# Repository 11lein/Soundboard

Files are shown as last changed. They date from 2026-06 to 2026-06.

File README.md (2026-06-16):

# 🚗 Soundboard für den Carbage Run

## 🎯 Motivation

Beim **Carbage Run** – einer Rallye mit Schrottautos – haben viele Teilnehmer Fanfaren, Megafone oder lustige Sounds abgespielt.  
Wir hatten zwar bereits ein Megafon mit Line-In und Bluetooth, aber:

> 🎛️ "Wenn ich hupen will, will ich auf einen Knopf hauen – nicht erst das Handy entsperren!"

Deshalb: ein eigenständiges Soundboard mit 25 Tasten, SD-Karte und Sofortreaktion.

---

## 📸 Vorschau

### Gehäuse (3D-gedruckt)

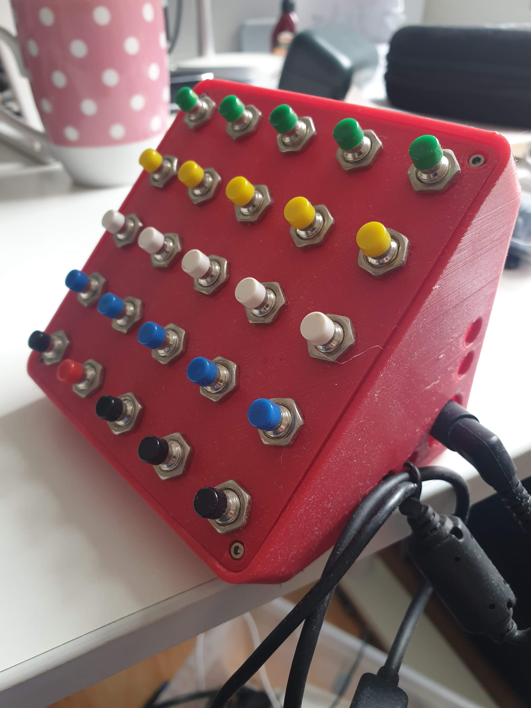
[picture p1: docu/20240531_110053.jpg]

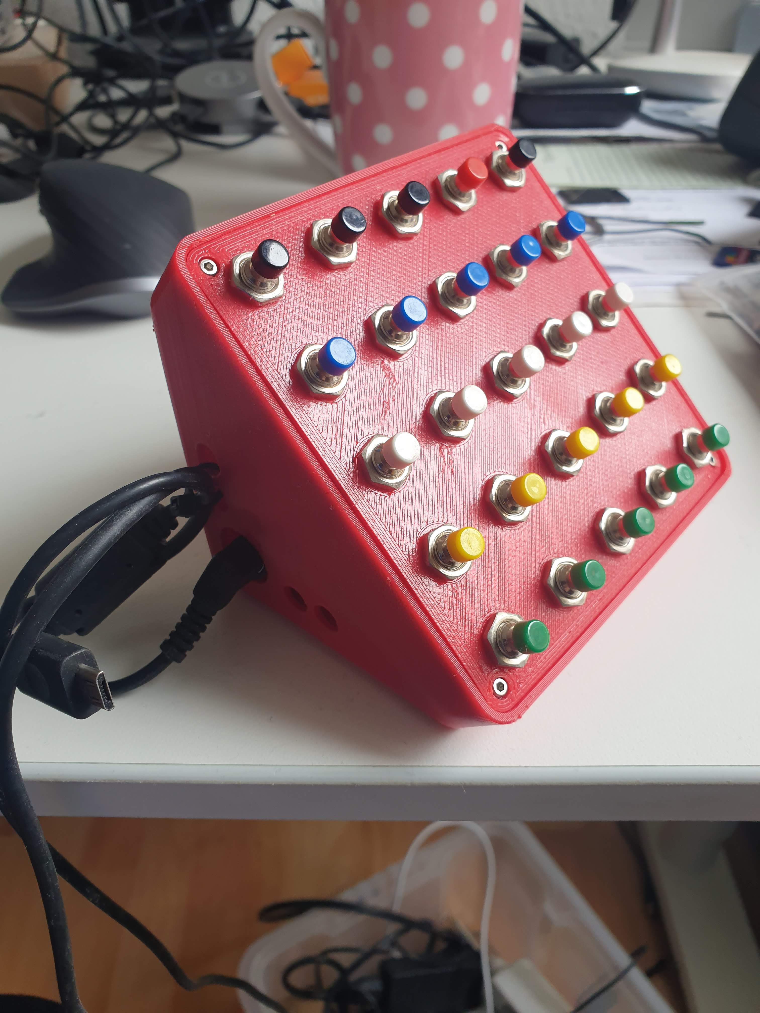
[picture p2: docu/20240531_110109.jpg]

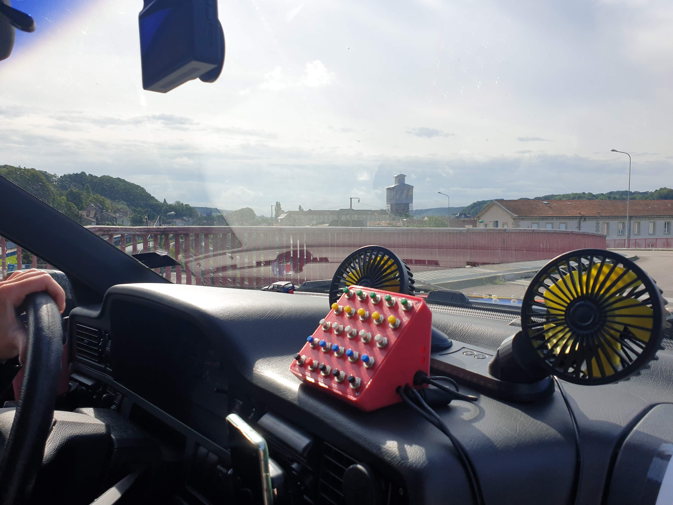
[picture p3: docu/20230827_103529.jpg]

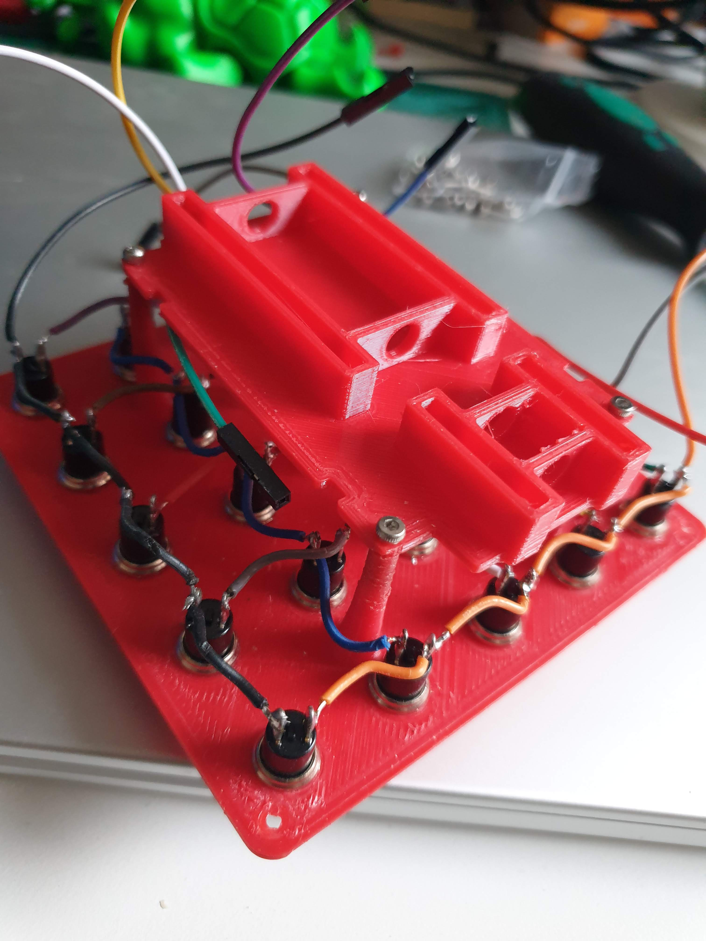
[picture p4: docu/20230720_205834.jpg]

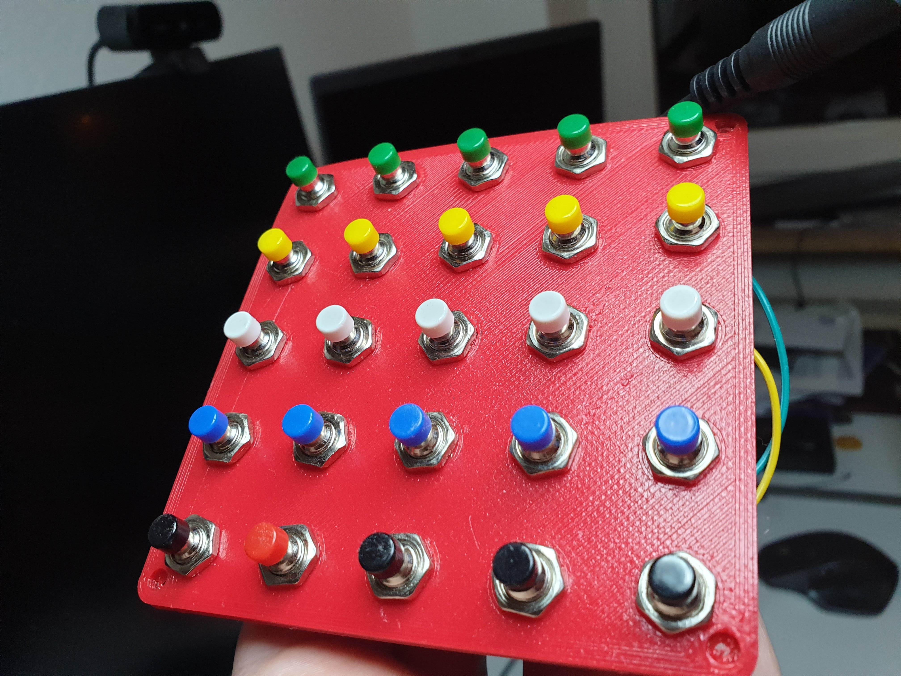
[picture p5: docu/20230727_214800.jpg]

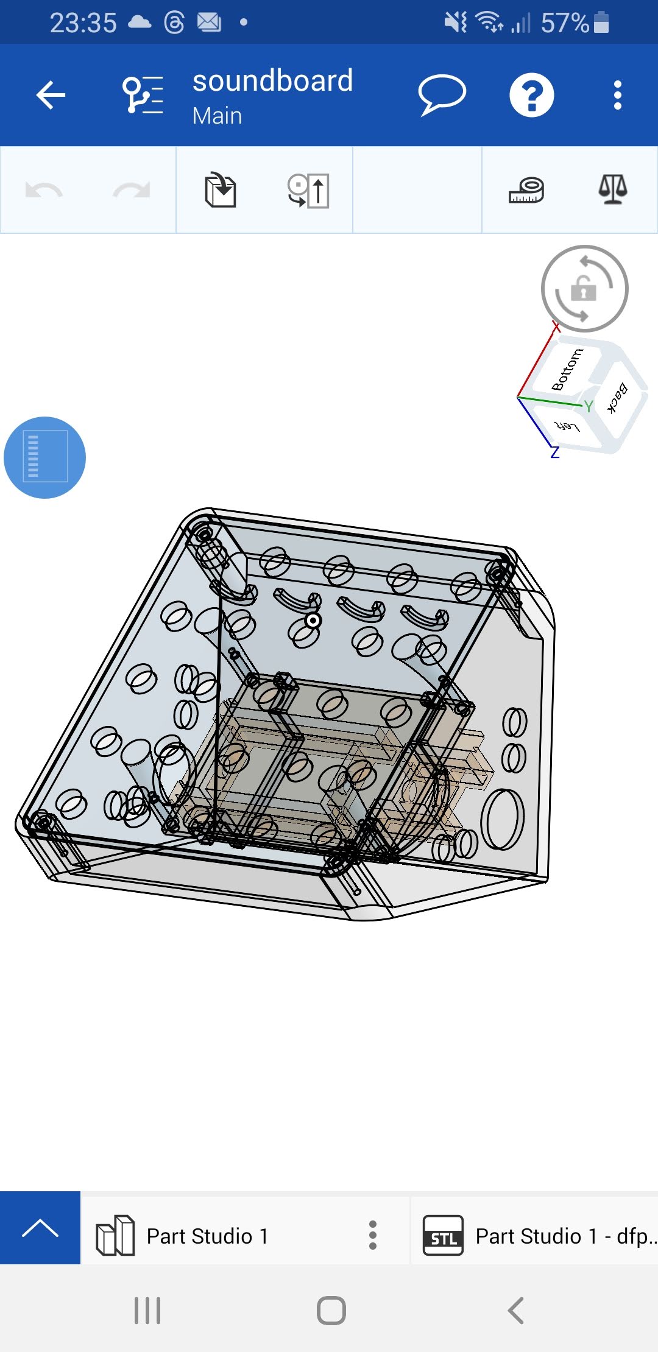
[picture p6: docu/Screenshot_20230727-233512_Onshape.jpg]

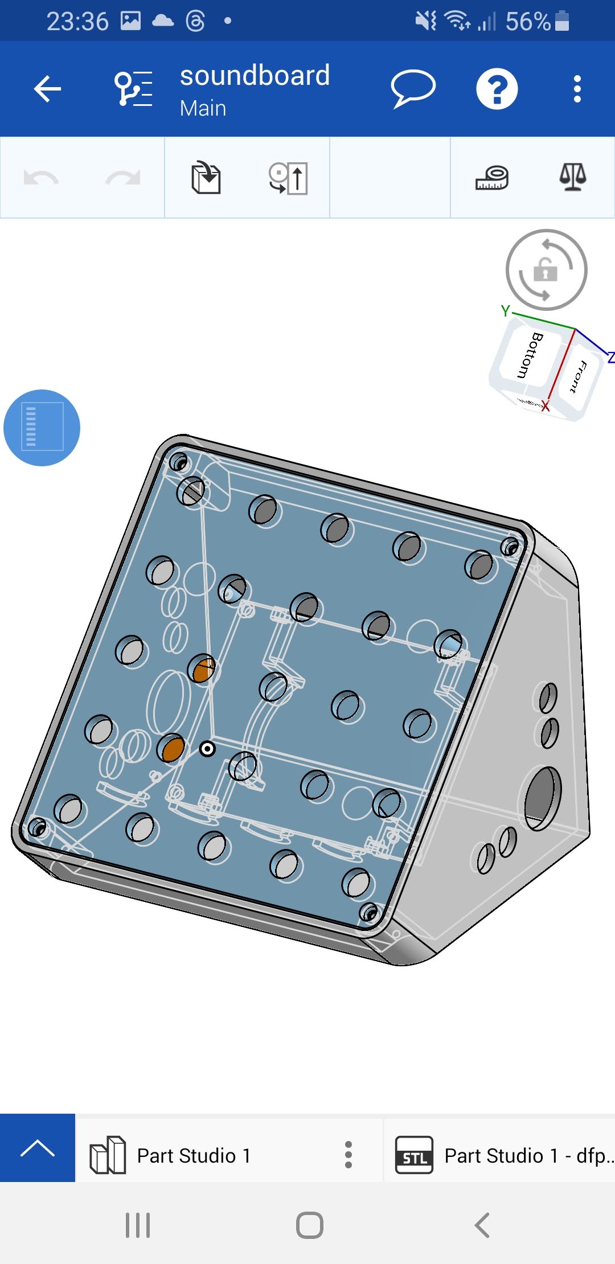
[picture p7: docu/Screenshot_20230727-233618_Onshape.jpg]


### Innenleben
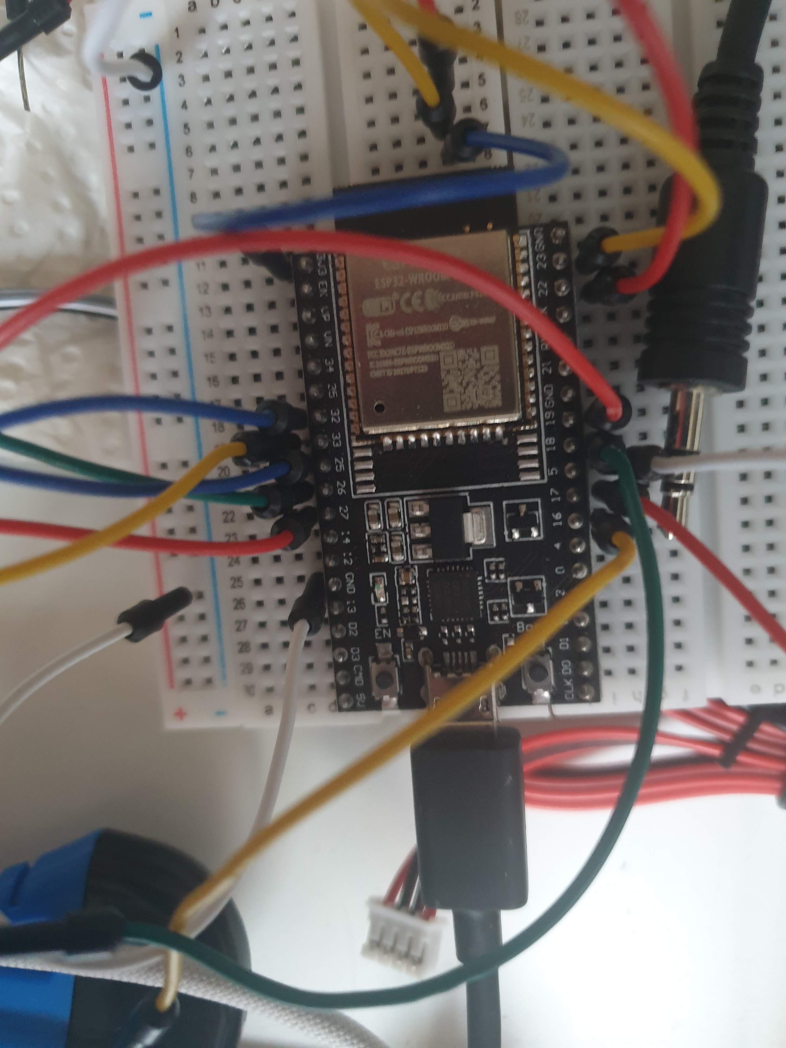
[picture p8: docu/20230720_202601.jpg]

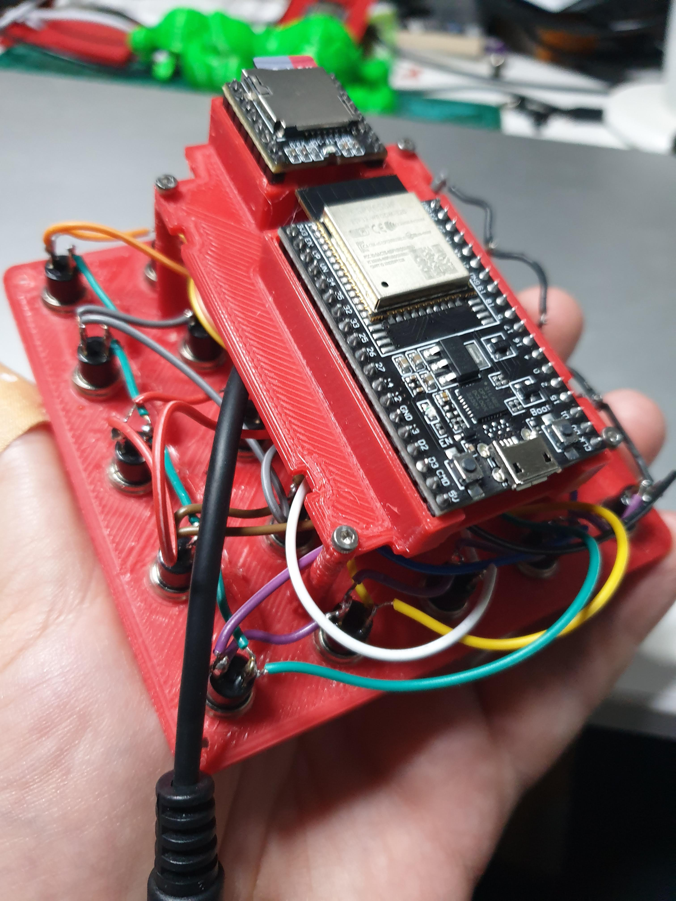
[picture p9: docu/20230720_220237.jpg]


> Alle Bilder findest du im Ordner `docu/`. Der aktuelle Verdrahtungsplan steht
> weiter unten im Abschnitt [Schaltung](#-schaltung).

---

## ⚙️ Features

- 🎵 **24 Soundtasten** (A–X) in 5×5 Matrix für direkte Soundauswahl
- 🔁 **Sechsfachbelegung:** `Y` = Mode-Taste + Halten → **144 Sounds** (6 Bänke)
- 💾 **DFPlayer Mini** spielt MP3s direkt von SD-Karte
- 📡 **Bluetooth**-Steuerung per Smartphone-App oder Terminal (alle 144 Tracks)
- 🧠 **ESP32** mit frei programmierbarer Logik
- 🧰 [**3D-gedrucktes Gehäuse**](https://cad.onshape.com/documents/51f835b686c64aa4e062ca5b/w/735ce97b22fc647d3e8dc544/e/93c6d67ebc2946beec692255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)

---

## 🧠 Schaltung

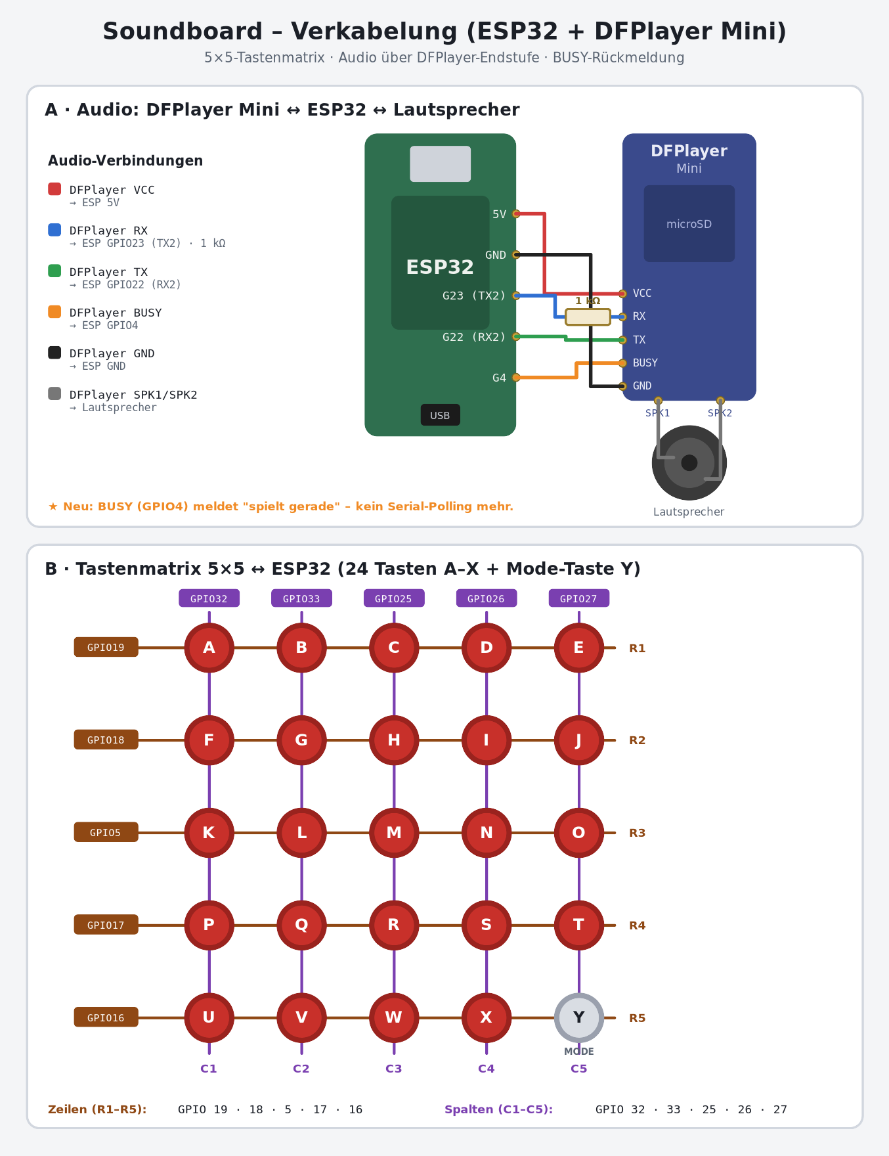
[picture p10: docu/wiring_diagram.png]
Verkabelung


> Aktueller Verdrahtungsplan mit **DFPlayer Mini** (inkl. **BUSY → GPIO4**) und der
> 5×5-Tastenmatrix. Quelle als SVG (`docu/wiring_diagram.svg`) bzw. zum Neuerzeugen
> `docu/gen_wiring.py` (rendert das SVG aus den Pin-Belegungen in `src/main.cpp`).
> Der frühere Wokwi-Entwurf (`docu/wokwi/`) nutzte ein SD-Kartenmodul als Platzhalter
> und ist nicht mehr aktuell.

### 🔘 Tastenanschlüsse

| Zeile (row) | ESP32 Pin |
|---|---|
| R1 | D19 |
| R2 | D18 |
| R3 | D5 |
| R4 | D17 |
| R5 | D16 |

| Spalte (col) | ESP32 Pin |
|---|---|
| C1 | D32 |
| C2 | D33 |
| C3 | D25 |
| C4 | D26 |
| C5 | D27 |

### 🎧 DFPlayer Mini Anschluss 
Für die korrekte Verkabelung siehe
[DFPlayer Mini Dokumentation](https://www.elektronik-kompendium.de/sites/praxis/bauteil_dfplayer-mini.htm)

| DFPlayer Pin | ESP32 Pin |
|---|---|
| TX | GPIO22 |
| RX | GPIO23 **(über 1 kΩ in Reihe)** |
| BUSY | GPIO4 |
| VCC | 5V |
| GND | GND |
|----| **Endstufe**|
| SPK1 | Left Audio  |
| GND | GND Audio |
| SPK2 | Right Audio |

> Der **1 kΩ-Widerstand** in der RX-Leitung (ESP-TX → DFPlayer-RX) dämpft Störungen
> und schützt den DFPlayer-Eingang – eine gängige Empfehlung für stabile UART-Kommunikation.

💾 SD-Karte:  
MP3-Dateien im MP3-Verzeichnis, benannt nach `Bank*100 + Position`:
Bank 1 = `0101`–`0124`, Bank 2 = `0201`–`0224`, … Bank 6 = `0601`–`0624` (24 pro Bank).

---

## 🎮 Bedienung

### Tasten (A–X) + Mode-Taste `Y`

`Y` spielt keinen Sound, sondern wählt die Bank-Gruppe. Eine Soundtaste **kurz** drücken oder **halten** wählt innerhalb der Gruppe die Bank:

| `Y`-Status | Soundtaste kurz | Soundtaste halten |
|---|---|---|
| – (Standard) | Bank 1 (`0101`–`0124`) | Bank 2 (`0201`–`0224`) |
| `Y` kurz tippen | Bank 3 (`0301`–`0324`) | Bank 4 (`0401`–`0424`) |
| `Y` halten | Bank 5 (`0501`–`0524`) | Bank 6 (`0601`–`0624`) |

- Tracknummer = **Bank × 100 + Position**. Taste **A** = Position 1, … **X** = Position 24.
- Der gewählte Mode gilt **für den nächsten Sound** und springt danach sofort auf Standard (Bank 1 & 2) zurück. Ohne Tastendruck resettet er automatisch **nach 10 s**; erneutes `Y` schaltet ebenfalls zurück.
- Dieselbe Taste während der Wiedergabe erneut drücken = **Stop**.

### 📡 Bluetooth-Befehle

Zahl (mit `\n`) an das Gerät `das_11lein` senden. Die Tracknummer enthält die Bank direkt – einfach die Nummer senden.

| Eingabe | Aktion |
|---|---|
| `101`–`624` | Track direkt abspielen (z. B. `305` = Bank 3, Taste E) |
| `700`–`6999` | Zusatz-/Parkplatz-Track (`0700`…), nur über die App, kein Hardware-Knopf |
| `7000`–`7100` | Lautstärke auf `(Wert−7000)` Prozent setzen (0–100 %) |
| `9999` | Stop |
| `9998` / `9997` / `9996` | Lautstärke 33 / 67 / 100 % (Kompatibilität) |
| `9995` | Neustart |

> Die Befehlscodes liegen bei `9999` absteigend – weit über jeder Tracknummer, daher keine Kollision.

Die zuletzt gesetzte Lautstärke wird im Flash (NVS) gespeichert und beim Booten
wiederhergestellt. Beim Verbinden sendet der ESP einmal `READY vol=<n>`, damit die
App den aktuellen Stand kennt. WiFi ist deaktiviert (das Gerät nutzt nur Bluetooth).

---

## 📂 Projektstruktur

```text
/
├── src/
│   ├── MP3/                # Arduino-Quellcode
│   └── main.cpp
├── printfiles/         # STL-Dateien für 3D-Druck
├── docu/               # Fotos, Schaltpläne, Screenshots
└── README.md

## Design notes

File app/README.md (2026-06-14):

# 📱 Soundboard Remote (Flutter, Android)

Flutter-App zur **Fernsteuerung des ESP32-Soundboards über Bluetooth Classic (SPP)**.
Spiegelt das physische Gerät: 6 Bänke, je ein 5×5-Raster mit den echten Tastenfarben.

<p align="center">
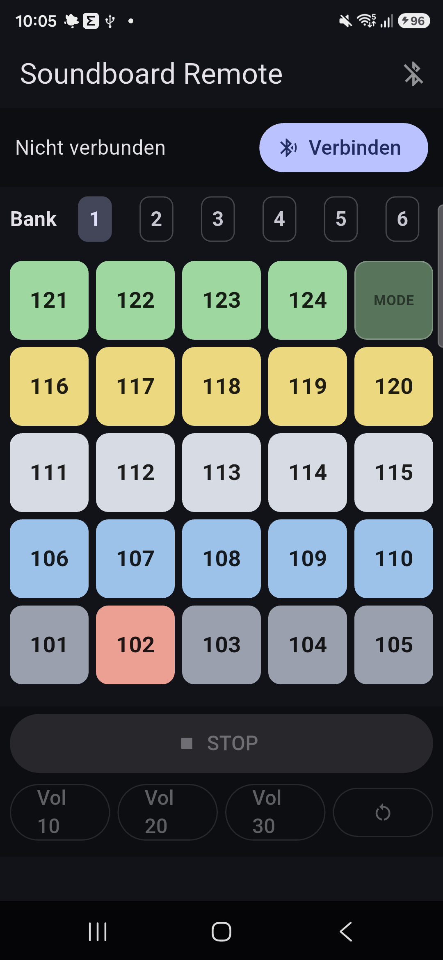
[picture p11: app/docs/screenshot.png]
Soundboard Remote – Bank 1 (Tracks 101–124)
  
</p>

## Funktion

- 🔵 **Verbinden** mit dem gekoppelten Gerät `das_11lein` (gekoppelte Geräte werden
  gelistet – vorher einmal in den Android-Bluetooth-Einstellungen koppeln).
- 🎛️ **6 Bänke** wählbar; pro Bank ein 5×5-Raster (Position unten links beginnend,
  oben rechts = Mode-Taste, nicht belegbar), eingefärbt nach der physischen
  Tastenfarbe.
- ▶️ Tippen sendet die Tracknummer **`Bank*100 + Position`** (`101`–`624`).
- 🔈 **Lautstärke** 10/20/30, ⏹ **Stop**, ↻ **Neustart** – als Befehle `9999`
  absteigend (siehe Firmware-Protokoll).

## Architektur

- `lib/soundboard_controller.dart` – Verbindungs-/Sende-Logik (`ChangeNotifier`),
  spricht über den Platform-Channel `soundboard/bt`.
- `lib/home_page.dart` – UI (Verbindungsleiste, Bank-Auswahl, Raster, Steuerung).
- `android/.../MainActivity.kt` – nativer **SPP-Channel** (BluetoothSocket via
  RFCOMM-UUID `00001101-…`). Bewusst kein Drittanbieter-BT-Plugin, damit der
  Build mit aktuellem AGP/Gradle sauber durchläuft.
- `assets/key-colors.json` – Tastenfarben (Kopie aus dem `mp3-sorter`-Tool).

Berechtigung: `BLUETOOTH_CONNECT` (Android 12+) wird zur Laufzeit über
`permission_handler` angefragt; nur gekoppelte Geräte, kein Scan/Location nötig.

## App installieren

### Android – APK direkt (empfohlen, kein Google Play nötig)

Eine fertig gebaute APK liegt im Repo unter `app/soundboard-remote.apk`.

1. APK auf das Telefon übertragen (USB-Kabel, Bluetooth-Dateiübertragung oder
   Cloud-Dienst deiner Wahl).
2. Auf dem Telefon: **Einstellungen → Apps → Sonderrechte → Unbekannte Quellen**
   (auf manchen Geräten: *Unbekannte Apps installieren*) für den Datei-Manager oder
   Browser aktivieren, mit dem du die APK öffnest.
3. Die APK antippen → installieren.
4. Nach der Installation einmal den Bluetooth-Namen `das_11lein` in den
   Android-Bluetooth-Einstellungen koppeln, dann die App öffnen.

> Android-Hilfe: [support.google.com – Apps aus anderen Quellen installieren](https://support.google.com/android/answer/7680439)

### iPhone / iOS – nicht direkt unterstützt

Bluetooth Classic (SPP/RFCOMM) wird von iOS **nicht unterstützt** – Apple erlaubt
App-seitig nur Bluetooth Low Energy (BLE) sowie proprietäre MFi-Protokolle.
Der ESP32 nutzt klassisches SPP, das auf iPhone grundsätzlich nicht aus Apps
heraus erreichbar ist (weder über den App Store noch per Sideload).

Optionen, falls du doch ein iOS-Gerät nutzen möchtest:

- **ESP32 auf BLE umrüsten**: Die Firmware auf BLE-UART (z. B. Nordic UART Service)
  umstellen; dann kann eine angepasste Flutter-App über `flutter_blue_plus` sprechen.
  Aufwand: mittlerer Firmware-Umbau.
- **Webbrowser-Steuerung**: ESP32 als WLAN-Access-Point mit einer kleinen
  Web-Seite; dann reicht Safari auf dem iPhone. Kein Bluetooth nötig.

> iOS-Referenz zu Bluetooth-Einschränkungen: [developer.apple.com – Core Bluetooth](https://developer.apple.com/documentation/corebluetooth)

---

## Selbst bauen & Installieren

> ⚠️ **Wichtig:** Android-/Gradle-Builds scheitern an Leerzeichen/Klammern im Pfad.
> Dieses Repo liegt unter `…/Soundboard (Kopie)/`, daher **nicht hier direkt
> bauen**. Projekt an einen Pfad **ohne Leerzeichen** kopieren (z. B.
> `~/soundboard_remote`) und dort bauen.

Voraussetzungen: Flutter SDK, Android SDK (`platforms;android-35`,
`build-tools;35.0.0`), **JDK 17** (eine JRE reicht nicht – `javac` nötig).

```bash
cp -r app ~/soundboard_remote && cd ~/soundboard_remote
export JAVA_HOME=/pfad/zur/jdk-17
flutter pub get
flutter build apk --release        # build/app/outputs/flutter-apk/app-release.apk
# auf ein angeschlossenes Telefon:
flutter install                    # oder: adb install -r app-release.apk
```

## Protokoll (muss zur Firmware passen)

| Senden | Wirkung |
|---|---|
| `101`–`624` | Track abspielen (`Bank*100 + Position`) |
| `9999` | Stop |
| `9998` / `9997` / `9996` | Lautstärke 10 / 20 / 30 |
| `9995` | Neustart |

Jeweils als ASCII-Zahl mit abschließendem `\n`.

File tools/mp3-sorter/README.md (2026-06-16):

# 🎚️ MP3 Sorter

Plattformübergreifendes Desktop-Tool (Mac / Linux / Windows) zum Sortieren der
Soundboard-MP3s per **Drag & Drop**. Die Dateien werden für das DFPlayer-Schema
`Bank*100 + Position` vorbereitet – Bank 1 = `0101`–`0124`, … Bank 6 =
`0601`–`0624` (6 Bänke × 24 = 144 Slots).

## Features

- 🖱️ **Drag & Drop:** Ordner oder MP3s ins Fenster ziehen zum Laden/Hinzufügen,
  Zeilen ziehen zum Umsortieren.
- 🔢 **Prefix-Sortierung:** Dateien mit gültigem `Bank*100+Pos`-Prefix (z. B.
  `0101_`, `0305_`) landen auf ihrem Slot; Dateien ohne (oder mit altem) Prefix
  werden alphabetisch dahinter einsortiert.
- 🏦 **Ansicht wie das PDF:** **ein** 5×5-Raster (dem Kasten nachempfunden, unten
  links beginnend, oben rechts die nicht belegbare Mode-Taste). Jede Taste zeigt
  **6 Zeilen** – eine je Bank – mit Dateiname (ohne Prefix/Endung) und
  **Play-Knopf** statt Nummer. Zellen sind nach der physischen Tastenfarbe
  eingefärbt.
- 🅿️ **Parkplätze:** Dateien **ohne** gültigen Prefix landen unten in Parkplätzen
  (Reihen aus 5 Boxen × 6 Zeilen, alphabetisch, mit Play). Zieht man eine Datei
  aus dem Raster hierher, wird ihr **Prefix entfernt** (sie wird wieder unsortiert).
- 🎨 **Farb-Kodierung:** Die physische Tastenfarbe (oben Grün, dann Gelb, Weiß,
  Blau, unten Schwarz – 2. von links Rot) liegt als
  [`lib/key-colors.json`](lib/key-colors.json) im Projekt und färbt Raster und PDF.
- ✏️ **Umbenennen (Suchen & Ersetzen):** Button öffnet einen Dialog mit
  Suchen/Ersetzen, **Regex**- und **Groß/Klein**-Checkbox (Default: ignoriert).
  Eine **2-Spalten-Vorschau** zeigt nur die betroffenen Dateien zum Bestätigen.
- ⚡ **Quick-Rename:** **Doppelklick** auf einen Titel benennt ihn direkt inline
  um (Enter = speichern, Esc = abbrechen).
- 🗑️ **Papierkorb:** Eine Kachel unten; hierhin gezogene Dateien werden beim
  **Final speichern** von der Festplatte gelöscht (mit ↩ Wiederherstellen je Eintrag).
- ⏱️ **Hover-Info:** Beim Überfahren einer Zeile werden **Dauer und Bitrate** der MP3 angezeigt.
- 📋 **Liste exportieren:** Schreibt platzierte **und geparkte** Titel als JSON
  (`soundboard-liste_…json`, Nummer → Titel) – zum Import in die App. Parkplätze
  bekommen dabei alphabetisch die Nummern **`700`+** (nur in der App nutzbar).
- 📥 **Liste importieren:** Lädt eine (in der App bearbeitete) Titel-JSON und
  überträgt die Titel auf die Dateien der passenden Slots – das anschließende
  **Final speichern** benennt entsprechend um (Round-Trip App ⇄ Sorter).
- 💳 **Auf SD-Karte schieben:** Wechseldatenträger auswählen, optional **vorher
  formatieren** (mit Nachfrage; sofern das OS es unterstützt), dann die Dateien in
  den `MP3/`-Ordner der Karte kopieren – platzierte als `0101_…`, geparkte als `0700_…`.
- 🔄 **Aktualisieren:** Liest den aktuellen Ordner neu von der Platte (neue/entfernte
  Dateien) und behält die Anordnung. Der **zuletzt geöffnete Ordner** wird gemerkt
  und beim Start automatisch wieder geöffnet.
- ▶️ **Vorhören:** Play-Knopf pro Zeile, der während der Wiedergabe zur Pause
  wird. Ein anderer Sound stoppt alle übrigen und setzt sie auf 0 s zurück – nur
  der aktuelle Titel merkt sich seine Pause.
- 🖨️ **PDF-Export & Vorschau (A4 quer):** Erzeugt eine Belegungs-Übersicht als
  5×5-Raster (mit den Tastenfarben als Hintergrund), wobei **jede Tastenzelle
  alle 6 Bänke** untereinander zeigt (Bank-Nummer + Dateiname **ohne**
  Prefix/Endung, einzeilig abgeschnitten, kein Umbruch). Ohne Überschrift, Zellen
  exakt 6 Zeilen hoch (Tabelle nicht seitenfüllend). **👁️ Vorschau** öffnet das
  fertige PDF in einem Fenster, bevor du speicherst.
- 💾 **Zwischenspeichern:** Der aktuelle Stand wird als `.mp3sorter.json` im
  Ordner gespeichert – **ohne** die Dateien anzufassen. Beim erneuten Öffnen
  wird dieser Entwurf wiederhergestellt.
- ✅ **Final speichern:** Erst hier werden die Dateien auf der Festplatte
  umbenannt (4-stelliger Prefix `NNNN_`). Kollisionssicher durch zweiphasiges
  Umbenennen (z. B. bei einem Tausch).

## Starten per Doppelklick

Voraussetzung: **Node.js/npm** ist installiert (https://nodejs.org). Beim ersten
Start werden die Abhängigkeiten automatisch geholt.

| Betriebssystem | Datei doppelklicken |
|---|---|
| 🪟 Windows | `start.bat` |
| 🍎 macOS | `start.command` |
| 🐧 Linux | `start.sh` |

> - **macOS:** Beim ersten Mal evtl. Rechtsklick → „Öffnen" (Gatekeeper).
> - **Linux:** Im Dateimanager ggf. „Ausführen erlauben" aktivieren bzw. beim
>   Doppelklick „Run/Ausführen" wählen.

## Start (Entwicklung / Terminal)

```bash
cd tools/mp3-sorter
npm install
npm start
```

> Hinweis Linux: Falls `ELECTRON_RUN_AS_NODE` in der Umgebung gesetzt ist, vorher
> entfernen: `env -u ELECTRON_RUN_AS_NODE npm start` (die Doppelklick-Starter
> erledigen das bereits selbst).

## Tests

```bash
npm test          # Unit-Tests der Sortier-/Namenslogik (node --test)
npm run test:smoke   # Electron-Smoketest: prüft, dass window.api vollständig
                     # bereitsteht und der "Ordner öffnen"-IPC-Pfad funktioniert
```

> Der Smoketest braucht eine Anzeige (DISPLAY) und ein echtes Electron; in
> Umgebungen mit gesetztem `ELECTRON_RUN_AS_NODE` davor entfernen.

## Installer bauen

```bash
npm run dist     # erzeugt dmg (mac) / nsis (win) / AppImage (linux) in dist/
```

## So funktioniert das Umbenennen

`finalName(slot, datei)` entfernt einen vorhandenen `NNNN_`-Prefix und setzt den
neuen `Bank*100+Pos`-Prefix davor – der beschreibende Teil bleibt erhalten:

```
Slot 1  + "0099_clownhorn.mp3"  ->  "0101_clownhorn.mp3"   (Bank 1, Pos 1)
Slot 25 + "airhorn.mp3"          ->  "0201_airhorn.mp3"     (Bank 2, Pos 1)
```

Die eigentliche Sortier-/Namenslogik liegt in [`lib/naming.js`](lib/naming.js)
und ist unabhängig von der GUI testbar.

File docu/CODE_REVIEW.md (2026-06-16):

# Code-Review: Soundboard

Analyse des Gesamtprojekts (ESP32-Firmware, Flutter-App, Electron-MP3-Sorter)
nach **Performance**, **Sicherheit**, **Coding-Guidelines** und **Linting**,
plus eine Bestandsaufnahme der Code-Kommentierung. Stand: 2026-06.

> Hinweis zur Verifikation: In der Review-/Web-Umgebung waren nur **Node.js +
> npm** verfügbar. Das Electron-Tool ist daher voll getestet (Unit-Tests,
> ESLint, Smoke-Test). **Flutter/Dart** und **PlatformIO** fehlten, d.h.
> Firmware und App konnten hier *nicht* kompiliert werden – Änderungen daran
> wurden bewusst konservativ gehalten und müssen lokal mit `flutter analyze` /
> `flutter test` bzw. `pio run` gegengeprüft werden.

## Gesamteindruck

Der Code ist insgesamt **überdurchschnittlich gepflegt**: durchdachte
Architektur, gute Trennung der drei Komponenten und – anders als oft – bereits
**dichte, sinnvolle Kommentierung** der nicht-offensichtlichen Stellen
(Bank-/Mode-Mathematik, deferred NVS-Write, BT-Overflow-Schutz, Reconnect-Logik,
PDF-Layout). Die wesentlichen Lücken lagen weniger bei „fehlenden Kommentaren"
als bei **fehlendem Linting** (Electron) und einem **inkonsistenten Path-Handling**
(Electron) sowie einer **sehr großen UI-Datei** (`app/lib/home_page.dart`).

| Komponente | Performance | Sicherheit | Guidelines | Linting |
|---|---|---|---|---|
| Firmware (`src/main.cpp`) | gut | gut (per Design) | gut | – (kein C++-Linter eingerichtet) |
| Flutter-App (`app/`) | gut | gut | mittel (Monolith) | flutter_lints (Default) |
| Electron (`tools/mp3-sorter/`) | gut | mittel → **gehärtet** | gut | **fehlte → eingeführt** |

---

## 1. Firmware — `src/main.cpp`

ESP32 / Arduino, ~330 Zeilen, eine `.cpp`. Sehr klar gegliedert und gut
kommentiert.

### Performance
- **Keine blockierenden Delays im `loop()`**; Timing über `millis()`-Stempel.
  Das einzige `delay(1000)` steckt in der DFPlayer-Init-Retry-Schleife in
  `setup()` (einmalig beim Boot) – akzeptabel und kommentiert.
- **Deferred NVS-Write** für die Lautstärke (`volumeDirty` + `VOLUME_SAVE_DELAY_MS`,
  `main.cpp:88`) verhindert Flash-Blockaden bei schnellem +5/−5-Tippen. Sehr gut.
- **Nicht-blockierender BT-Zeilenleser** mit fixem 8-Byte-Puffer (`main.cpp:256`)
  – keine Heap-Fragmentierung, sauberer Overflow-Schutz.

### Sicherheit
- **Kein Bluetooth-Auth** und **Remote-Reset (`9995`)** ohne Bestätigung
  (`main.cpp:305`). Das ist **bewusst so** (vertrauenswürdiges Umfeld, ein
  Carbage-Run-Auto) und in `AGENTS.md` dokumentiert. Threat-Model akzeptiert;
  als Restrisiko vermerkt (ein gekoppeltes Gerät kann Stop/Volume/Reset senden).
- **Eingabevalidierung** ist solide: `atoi` + `if (input > 0)`, Bereichsprüfung
  für Tracks/Volume (`main.cpp:285`, `310`), Overflow-Zeilen werden verworfen
  statt abgeschnitten (`main.cpp:264`, `329`). Nicht existente Tracks lässt der
  DFPlayer still fallen (kein Crash).

### Coding-Guidelines
- `keys`, `rowPins`, `colPins` (`main.cpp:57–65`) sind nicht `const`. **Bewusst
  nicht geändert:** der `Keypad`-Konstruktor nimmt nicht-`const`-Zeiger
  (`char*`, `byte*`), `const`-Pin-Arrays würden ohne Cast die Kompilierung
  brechen. Niedrige Priorität.
- Leichte Duplizierung bei den Kompat-Volume-Befehlen (`main.cpp:290–303`) –
  vertretbar, gut lesbar; kein Umbau nötig.
- Naming `mySerial` / `myDFPlayer` ist Arduino-üblich; rein kosmetisch.

### Umgesetzt (Kommentare, null Verhaltensänderung)
- `isPlaying()`: Unzuverlässigkeit des BUSY-Pins explizit dokumentiert und warum
  er nur für den Stop-Toggle taugt.
- Erläutert, warum `lastKey` nach einem Stop genullt wird.

---

## 2. Flutter-App — `app/`

Sauberes `ChangeNotifier`-Modell. `soundboard_controller.dart` (BT-State,
Protokoll, Reconnect-Watchdog) ist **vorbildlich kommentiert**. Native SPP-Anbindung
in Kotlin (`MainActivity.kt`) mit korrektem Threading und Exception-Handling.

### Performance
- `ListenableBuilder` auf `[controller, AppSettings]` (`home_page.dart`), Tabs via
  `KeepAlive`/`AutomaticKeepAliveClientMixin` am Leben gehalten – gut.
- **Watchdog 700 ms** (`soundboard_controller.dart:125`) mit 3-s-Throttle für
  stille Reconnects – vernünftig. *Empfehlung:* exponentielles Backoff, falls das
  Gerät dauerhaft aus ist (Akku).
- `wrapKeyTitle()` lief bisher pro Tile/Frame. Durch Auslagern als reine Funktion
  ist es jetzt **cachebar** (Empfehlung: Ergebnis pro `TrackEntry` memoisieren).

### Sicherheit
- Laufzeit-Berechtigungen (`Permission.bluetoothConnect`) inkl. „dauerhaft
  abgelehnt"-Pfad sauber behandelt (`soundboard_controller.dart:317`).
- Nur **gekoppelte** Geräte, fixe SPP-UUID; keine Secrets in `SharedPreferences`.
- *Empfehlung (Kotlin):* `s.connect()` ohne Timeout (`MainActivity.kt`) kann den
  Connect-Thread bis zum OS-Timeout (~20 s) hängen lassen → `withTimeoutOrNull`.

### Coding-Guidelines
- **Hauptbefund:** `home_page.dart` war mit **1193 Zeilen** ein Monolith
  (Grid, Controls, Dialoge, Suche, Menüs in einem `State`).
- Vereinzelt stille `catch (_)` ohne Begründung.

### Linting
- `analysis_options.yaml` nutzte nur das Default-`flutter_lints` ohne eigene
  Regeln.

### Umgesetzt
- **`home_page.dart` verschlankt:** die drei sicher und mechanisch
  extrahierbaren Teile nach `lib/widgets/` ausgelagert – `wrapKeyTitle()`
  (`key_title.dart`, jetzt unit-getestet), `KeepAlive`, `PlayPulse`.
  Verhaltensneutral (Verbatim-Move + Referenz-Rename).
- **Test** `test/key_title_test.dart` für die Umbruch-Invarianten.
- **Lint-Regeln** in `analysis_options.yaml` aktiviert (single quotes, const,
  final locals, no print, …) – stilkonform.
- Begründungs-Kommentare an den verbleibenden `catch (_)` im Controller.

### Offene Empfehlung (Follow-up mit Compiler)
Der tiefere Split der **zustandsbehafteten** Builder-Methoden
(`_grid`/`_key`/`_controls`/`_bankSelector`) in eigene `StatelessWidget`s wurde
**bewusst nicht** in dieser Umgebung gemacht: er erfordert das Durchreichen von
`controller` und etlichen Callbacks und ist ohne `flutter analyze`/Gerätetest
nicht verifizierbar (zu hohes Regressionsrisiko für eine reine Android-App).

---

## 3. Electron-MP3-Sorter — `tools/mp3-sorter/`

`main.js` (IPC/Dateioperationen), `preload.js` (contextBridge), `renderer/`
(UI), `lib/naming.js` (geteilte, gut getestete Namenslogik).

### Sicherheit (Electron-spezifisch)
**Solide Grundlage:** `contextIsolation: true`, `nodeIntegration: false`
(`main.js:91`), restriktive **CSP** (`renderer/index.html`), kein Remote-Content,
`execFile` mit Array-Args (keine Shell-Injection), Preload als enge Whitelist.

**Befund – inkonsistentes Path-Handling (behoben):** `copy-into` nutzte bereits
`path.basename`, aber `delete-files`, `apply-renames`, `copy-to-card`, `mp3-info`
und `file-url` verketteten den vom Renderer gelieferten Namen direkt mit dem
Ordner. In der Praxis kommen die Namen aus dem Verzeichnis-Listing (harmlos),
aber der Main-Prozess sollte dem Renderer nicht blind vertrauen → **Defense in
Depth**.

### Performance
- Dateioperationen durchweg **async** (`fs/promises`), kein Sync-I/O.
- `render()` baut das DOM komplett neu (144 Slots) – bei dieser festen Größe
  unkritisch; dokumentiert.
- `htmlToPdf()` startet pro Aufruf ein Offscreen-Fenster – selten/aktiv
  ausgelöst, Pooling wäre Overkill (jetzt als Kommentar begründet).

### Coding-Guidelines
- Gut benannte IPC-Handler, `lib/naming.js` isoliert und 100 % testabgedeckt.
- **Duplizierung:** vier nahezu identische Overlay-/Dialog-Blöcke im Renderer.

### Linting
- **Es gab kein ESLint-Setup** – die explizit angefragte Lücke.

### Umgesetzt (vollständig verifiziert)
- **`lib/safe-path.js` (`safeJoin`)** eingeführt und in *allen* betroffenen
  IPC-Handlern angewandt; erzwingt, dass jede Dateioperation im gewählten Ordner
  bleibt. Mit Unit-Test `test/safe-path.test.js`.
- **ESLint Flat-Config** (`eslint.config.js`) für die drei Scopes (Node, UMD,
  Browser), `npm run lint`-Script und Dev-Deps; einzigen Verstoß behoben
  (ungenutzter `naming`-Import in `main.js`).
- **`renderer/dialog.js` (`showDialog`)** extrahiert; Export-/Import-/Diff-/
  Format-Prompts darauf umgestellt (Dedup ~80 Zeilen, konsistentes Markup).
- Perf-Kommentar an `htmlToPdf()`.

**Verifikation:** `npm test` → **16/16 grün** · `npm run lint` → **sauber** ·
`npm run test:smoke` (xvfb) → **alle Checks grün**, inkl. „no preload/renderer
errors" und PDF-Vorschau (bestätigt, dass `dialog.js` korrekt eingebunden ist).

---

## Zusammenfassung der umgesetzten Änderungen

| Bereich | Änderung | Verifiziert? |
|---|---|---|
| Electron | `safeJoin` Path-Hardening + Test | ✅ Unit-Test |
| Electron | ESLint Flat-Config + `lint`-Script | ✅ `npm run lint` |
| Electron | `showDialog`-Dedup | ✅ Smoke-Test |
| Flutter | `home_page.dart` → `widgets/` (wrapKeyTitle/KeepAlive/PlayPulse) | ⚠️ lokal `flutter test`/`analyze` |
| Flutter | Lint-Regeln + Controller-Kommentare | ⚠️ lokal `flutter analyze` |
| Firmware | Kommentare (BUSY-Pin, Stop-Toggle) | ⚠️ lokal `pio run` |

## Empfohlene Follow-ups (nicht umgesetzt)
1. **Flutter:** `home_page.dart` weiter aufteilen (Grid/Controls als eigene
   Widgets) – mit Compiler/Gerätetest.
2. **Flutter:** `wrapKeyTitle`-Ergebnis pro `TrackEntry` cachen; Reconnect-Backoff;
   Connect-Timeout im Kotlin-Channel.
3. **Firmware:** optional ESP-seitig die Befehls-Annahme härten (z.B. Reset nur
   nach Bestätigungs-Sequenz), falls das Threat-Model strenger wird.
4. **CI:** GitHub-Action, die zumindest `npm test` + `npm run lint` (Electron)
   und – mit Flutter-Setup – `flutter analyze`/`flutter test` fährt.

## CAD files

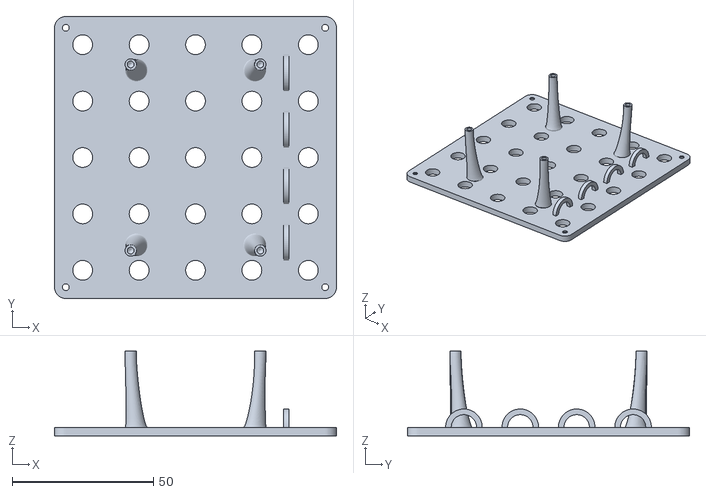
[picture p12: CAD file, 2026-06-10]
printfiles/soundboard.stl
100.0 x 100.0 x 30.0

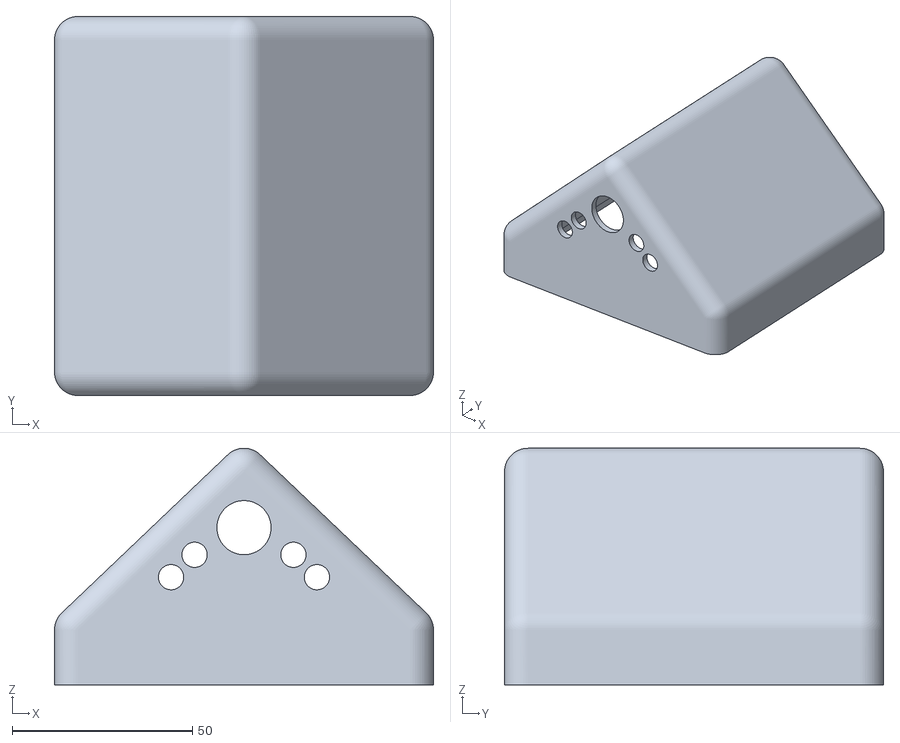
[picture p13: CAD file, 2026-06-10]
printfiles/body.stl
105.0 x 105.0 x 65.5

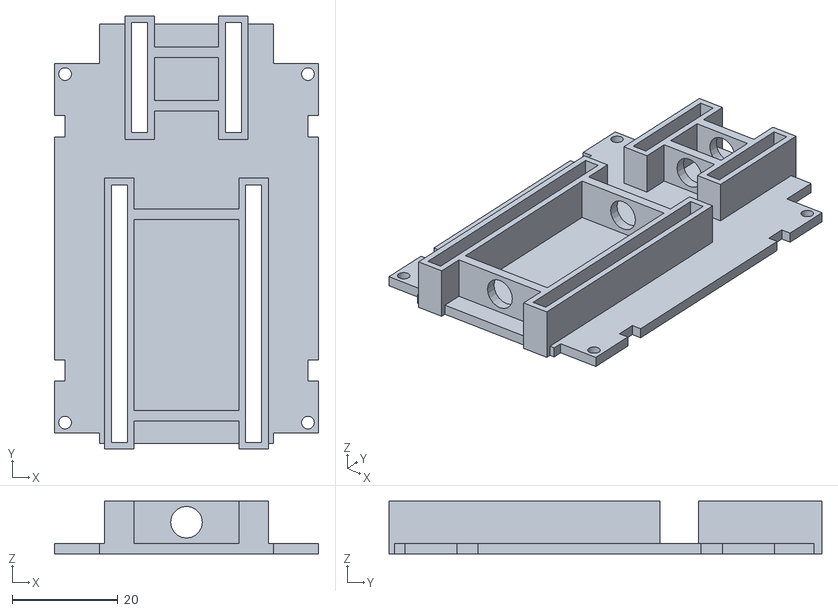
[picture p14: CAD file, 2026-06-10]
printfiles/soundboard_tray.stl
50.0 x 82.0 x 10.0

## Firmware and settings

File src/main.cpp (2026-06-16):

#include "Arduino.h"
#include <Keypad.h>
#include <DFPlayerMini_Fast.h>
#include "BluetoothSerial.h"
#include <esp_wifi.h>
#include <Preferences.h>

// --- Configuration ---
const char *BT_NAME = "das_11lein";  // Bluetooth device name
const int KEYS_PER_BANK = 24;        // sound keys A..X (Y is the mode button)
const int MAX_VOLUME = 30;           // DFPlayer volume range is 0..30
const int START_VOLUME_PCT = 100;    // boot volume as percent (100% = level 30)
const int HOLD_TIME_MS = 500;        // press duration that selects the 2nd bank
const int BUSY_PIN = 4;              // DFPlayer BUSY pin: LOW while a track plays
const char MODE_KEY = 'Y';           // this key selects the bank group, no sound
const unsigned long MODE_TIMEOUT_MS = 10000; // auto-reset to mode 0 after 10 s

// Mode (selected with the Y key) chooses a pair of banks; the sound key's
// hold then picks one of the pair. 24 keys x 6 banks = 144 tracks.
//   mode 0: banks 1 & 2   (Y not pressed, default)
//   mode 1: banks 3 & 4   (Y tapped)
//   mode 2: banks 5 & 6   (Y held)

const int NUM_BANKS = 6; // 6 banks of 24 keys = 144 tracks

// Track numbering encodes bank + position: track = bank*100 + key (1..24).
//   bank 1: 101..124   bank 2: 201..224   ...   bank 6: 601..624
// Files on the SD card are named accordingly (0101_*.mp3 ... 0624_*.mp3).

// Bluetooth protocol:
//   101..624   -> play that track directly (bank is encoded in the number)
//   7000..7100 -> set volume to (input-7000) percent (0..100%)
//   9995..9999 -> commands below (above any track number, descending)
const int CMD_VOLUME_SET_BASE = 7000; // 7000+pct sets volume to pct (0..100)
const int CMD_STOP = 9999;       // stop playback
const int CMD_VOLUME_LOW = 9998; // set volume to ~33% (compat: old "10")
const int CMD_VOLUME_MID = 9997; // set volume to ~67% (compat: old "20")
const int CMD_VOLUME_HIGH = 9996; // set volume to 100% (compat: old "30")
const int CMD_RESET = 9995;      // restart the ESP32

BluetoothSerial SerialBT;

// Persistent storage for the last-used volume (survives reboots).
Preferences prefs;
int currentVolumePct = START_VOLUME_PCT; // active volume as percent (0..100)
volatile bool btClientConnected = false; // set by the SPP callback on connect

// SPP event callback: flag a fresh connection so loop() can greet the client.
void btEventCallback(esp_spp_cb_event_t event, esp_spp_cb_param_t *param)
{
  if (event == ESP_SPP_SRV_OPEN_EVT)
    btClientConnected = true;
}

const byte ROWS = 5; // five rows
const byte COLS = 5; // five columns
char keys[ROWS][COLS] = {
    {'A', 'B', 'C', 'D', 'E'},
    {'F', 'G', 'H', 'I', 'J'},
    {'K', 'L', 'M', 'N', 'O'},
    {'P', 'Q', 'R', 'S', 'T'},
    {'U', 'V', 'W', 'X', 'Y'},
};
byte rowPins[ROWS] = {19, 18, 5, 17, 16};  // connect to the row pinouts of the keypad
byte colPins[COLS] = {32, 33, 25, 26, 27}; // connect to the column pinouts of the keypad

Keypad keypad = Keypad(makeKeymap(keys), rowPins, colPins, ROWS, COLS);
bool hold = false;
char lastKey = 0;

byte modeLevel = 0;             // 0,1,2 -> bank pairs (1&2, 3&4, 5&6)
bool yHold = false;            // true while the Y press is a long hold
unsigned long modeSetTime = 0; // millis() when the mode was last changed

HardwareSerial mySerial(2); // UART2, RX=22 TX=23

DFPlayerMini_Fast myDFPlayer;

// Read playback state from the BUSY pin (instant) instead of a serial query.
// BUSY is LOW while a track is playing, HIGH when idle.
// NOTE: this DFPlayer's BUSY signal is unreliable — it often reads idle ~1 s
// into a track and flickers. So we only use it for the momentary same-key
// "stop" toggle below (a missed read just means the toggle no-ops), never as a
// trustworthy "is something playing" indicator.
bool isPlaying()
{
  return digitalRead(BUSY_PIN) == LOW;
}

// Pending NVS save for the volume. Flash writes block ~10-20 ms, so we don't
// write on every +5/-5 step; loop() persists the value once it has settled.
bool volumeDirty = false;
unsigned long volumeChangedAt = 0;
const unsigned long VOLUME_SAVE_DELAY_MS = 1500;

// Apply a volume given in percent (0..100), map it to the DFPlayer's 0..30
// range, and mark it for a deferred NVS save (so rapid changes don't block).
void applyVolumePct(int pct)
{
  if (pct < 0) pct = 0;
  if (pct > 100) pct = 100;
  currentVolumePct = pct;
  int vol = (pct * MAX_VOLUME + 50) / 100; // percent -> 0..30 (rounded)
  myDFPlayer.volume(vol);
  volumeDirty = true;
  volumeChangedAt = millis();
}

void playTrack(int track)
{
  Serial.print(F("Track: "));
  Serial.println(track);
  myDFPlayer.playFromMP3Folder(track);
}

void setMode(byte level)
{
  modeLevel = level;
  modeSetTime = millis();
  Serial.print(F("Mode: "));
  Serial.println(modeLevel); // 0=banks 1&2, 1=banks 3&4, 2=banks 5&6
}

void keypadEvent(KeypadEvent key)
{
  KeyState state = keypad.getState();

  // --- Y is the mode button (no sound). Tap -> mode 1, hold -> mode 2.
  //     Pressing it again toggles back to mode 0 (also auto-resets after 10s).
  if (key == MODE_KEY)
  {
    switch (state)
    {
    case HOLD:
      yHold = true;
      break;
    case RELEASED:
      if (yHold)
        setMode(modeLevel == 2 ? 0 : 2); // Y held -> banks 5 & 6
      else
        setMode(modeLevel == 1 ? 0 : 1); // Y tapped -> banks 3 & 4
      yHold = false;
      break;
    default:
      break;
    }
    return;
  }

  // --- Sound keys A..X ---
  // Play on RELEASE: a tap plays bank A of the current group, holding past
  // HOLD_TIME_MS selects bank B. Pressing the same key again while it plays
  // stops it (toggle).
  switch (state)
  {
  case HOLD:
    hold = true;
    break;

  case RELEASED:
  {
    byte bankIndex = modeLevel * 2 + (hold ? 1 : 0);    // 0..5
    hold = false;
    int track = (bankIndex + 1) * 100 + (key - 'A' + 1); // 101..624

    if (isPlaying() && lastKey == key)
    { // same key pressed again → stop (toggle)
      myDFPlayer.stop();
      lastKey = 0; // clear it so the next press of this key plays again, not stops
    }
    else
    {
      lastKey = key;
      playTrack(track);
      if (modeLevel != 0)
        setMode(0); // back to banks 1 & 2 after every played sound
    }
    break;
  }

  default:
    break;
  }
}

void setup()
{
  Serial.begin(115200);

  // WiFi is unused. The sketch never calls WiFi.begin(), so the radio is never
  // brought up, but we stop+deinit the driver explicitly to guarantee it draws
  // no power and to document the intent. These are harmless no-ops returning
  // ESP_ERR_WIFI_NOT_INIT if WiFi was never started. (Using the ESP-IDF calls
  // directly avoids linking the heavy Arduino <WiFi.h> library.)
  esp_wifi_stop();
  esp_wifi_deinit();

  mySerial.begin(9600, SERIAL_8N1, 22, 23);
  pinMode(BUSY_PIN, INPUT_PULLUP);

  // Try to bring up the DFPlayer; reboot after a few failed attempts rather
  // than hanging forever on a transient SD-card or power glitch at cold boot.
  byte attempts = 0;
  while (!myDFPlayer.begin(mySerial))
  {
    Serial.println(F("DFPlayer not found - check connection and SD card"));
    if (++attempts >= 5)
    {
      Serial.println(F("DFPlayer init failed, restarting..."));
      ESP.restart();
    }
    delay(1000);
  }

  SerialBT.register_callback(btEventCallback); // greet clients on connect
  if (!SerialBT.begin(BT_NAME))
  {
    Serial.println(F("Bluetooth init failed"));
  }

  keypad.addEventListener(keypadEvent); // Add an event listener for this keypad
  keypad.setHoldTime(HOLD_TIME_MS);

  Serial.println(F("DFPlayer Mini online."));

  // Restore the last-used volume from NVS (default START_VOLUME_PCT on 1st boot).
  prefs.begin("soundboard", false);
  applyVolumePct(prefs.getInt("volpct", START_VOLUME_PCT));
  volumeDirty = false; // just restored – nothing to write back
}

void loop()
{
  keypad.getKey();

  // Auto-reset the mode to default (banks 1 & 2) 10 s after it was selected.
  if (modeLevel != 0 && millis() - modeSetTime > MODE_TIMEOUT_MS)
    setMode(0);

  // Greet a freshly connected client with the current state so the app can
  // show the real volume instead of guessing. Set by the SPP callback.
  if (btClientConnected)
  {
    btClientConnected = false;
    SerialBT.println("READY vol=" + String(currentVolumePct));
  }

  // Persist a settled volume change to NVS (deferred to avoid blocking flash
  // writes during rapid +5/-5 tapping).
  if (volumeDirty && millis() - volumeChangedAt > VOLUME_SAVE_DELAY_MS)
  {
    prefs.putInt("volpct", currentVolumePct);
    volumeDirty = false;
  }

  // Non-blocking BT line reader (fixed buffer, no heap fragmentation).
  // overflow=true marks a line longer than the buffer: we keep discarding its
  // bytes until the next '\n' so a too-long line is dropped instead of being
  // truncated and misinterpreted as a valid (but wrong) number.
  static char btBuffer[8];
  static byte btLen = 0;
  static bool overflow = false;
  while (SerialBT.available())
  {
    char c = SerialBT.read();
    if (c == '\n')
    {
      if (overflow)
      {
        SerialBT.println("Ignored (too long)");
        overflow = false;
        btLen = 0;
        continue;
      }
      btBuffer[btLen] = '\0';
      int input = atoi(btBuffer);
      btLen = 0;

      Serial.print(F("BT input: "));
      Serial.println(input);

      if (input > 0)
      {
        if (input == CMD_STOP)
        {
          myDFPlayer.stop();
          SerialBT.println("Stopped");
        }
        else if (input >= CMD_VOLUME_SET_BASE && input <= CMD_VOLUME_SET_BASE + 100)
        { // set volume to an exact percentage (0..100%)
          applyVolumePct(input - CMD_VOLUME_SET_BASE);
          SerialBT.println("Volume " + String(currentVolumePct) + "%");
        }
        else if (input == CMD_VOLUME_LOW)
        {
          applyVolumePct(33);
          SerialBT.println("Volume 33%");
        }
        else if (input == CMD_VOLUME_MID)
        {
          applyVolumePct(67);
          SerialBT.println("Volume 67%");
        }
        else if (input == CMD_VOLUME_HIGH)
        {
          applyVolumePct(100);
          SerialBT.println("Volume 100%");
        }
        else if (input == CMD_RESET)
        {
          SerialBT.println("reset");
          ESP.restart();
        }
        else if ((input / 100 >= 1 && input / 100 <= NUM_BANKS &&
                  input % 100 >= 1 && input % 100 <= KEYS_PER_BANK) ||
                 (input >= 700 && input < CMD_VOLUME_SET_BASE))
        { // bank track (101..624) OR an app-only extra/parked track (>=700,
          // not reachable from the keypad; played from the app's list view)
          Serial.println("Playing track: " + String(input));
          playTrack(input); // sends "PLAY <n>" to the app itself
        }
        else
        {
          SerialBT.println("Unknown: " + String(input));
        }
      }
    }
    else if (c != '\r')
    {
      if (btLen < sizeof(btBuffer) - 1)
        btBuffer[btLen++] = c;
      else
        overflow = true; // line exceeds the buffer → discard until newline
    }
  }
}

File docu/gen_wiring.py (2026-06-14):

#!/usr/bin/env python3
"""Generate a clean wiring diagram (SVG) for the ESP32 soundboard.

Two panels:
  A) Audio path: DFPlayer Mini <-> ESP32 <-> speaker (incl. the BUSY pin).
  B) 5x5 key matrix <-> ESP32 (row/column GPIOs).

Pins taken directly from src/main.cpp:
  rows  = GPIO 19,18,5,17,16   cols = GPIO 32,33,25,26,27
  DFPlayer: TX->GPIO22, RX->GPIO23, BUSY->GPIO4, VCC->5V, GND->GND
"""

W, H = 1000, 1300
parts = []

FONT = "DejaVu Sans"
MONO = "DejaVu Sans Mono"

# ---- palette ----
BG = "#f4f5f7"
BOARD = "#2f6f4f"        # ESP board green
BOARD_DK = "#24573e"
DFP = "#3a4a8c"          # DFPlayer blue
DFP_DK = "#2c3a6e"
SPK = "#3a3a3a"
KEY = "#c8302a"
KEY_DK = "#9a231e"
PAD = "#d9dde3"
INK = "#1b1f27"
MUTE = "#5b6573"

WIRE = {
    "5v": "#d23b3b",
    "gnd": "#222222",
    "tx": "#2e9e4f",
    "rx": "#2f6fd2",
    "busy": "#f08a24",
    "spk": "#777777",
    "row": "#8f4814",
    "col": "#7a3fb0",
}


def rect(x, y, w, h, fill, rx=8, stroke="none", sw=0, opacity=1):
    s = f' stroke="{stroke}" stroke-width="{sw}"' if stroke != "none" else ""
    parts.append(
        f'<rect x="{x}" y="{y}" width="{w}" height="{h}" rx="{rx}" '
        f'fill="{fill}" opacity="{opacity}"{s}/>'
    )


def text(x, y, s, size=15, fill=INK, anchor="start", weight="normal", font=FONT):
    parts.append(
        f'<text x="{x}" y="{y}" font-family="{font}" font-size="{size}" '
        f'fill="{fill}" text-anchor="{anchor}" font-weight="{weight}">{s}</text>'
    )


def wire(pts, color, w=4):
    d = "M " + " L ".join(f"{x},{y}" for x, y in pts)
    parts.append(
        f'<path d="{d}" fill="none" stroke="{color}" stroke-width="{w}" '
        f'stroke-linecap="round" stroke-linejoin="round"/>'
    )


def dot(x, y, color, r=5):
    parts.append(f'<circle cx="{x}" cy="{y}" r="{r}" fill="{color}"/>')


def pin(x, y, color="#caa23a"):
    parts.append(
        f'<circle cx="{x}" cy="{y}" r="4.5" fill="{color}" '
        f'stroke="#7a6320" stroke-width="1"/>'
    )


# ===== background =====
rect(0, 0, W, H, BG, rx=0)

# ===== title =====
text(W / 2, 44, "Soundboard – Verkabelung (ESP32 + DFPlayer Mini)",
     size=26, anchor="middle", weight="bold")
text(W / 2, 70, "5×5-Tastenmatrix · Audio über DFPlayer-Endstufe · BUSY-Rückmeldung",
     size=15, anchor="middle", fill=MUTE)

# =====================================================================
#  PANEL A — Audio path
# =====================================================================
pax, pay, paw, pah = 30, 96, 940, 496
rect(pax, pay, paw, pah, "#ffffff", rx=14, stroke="#d2d7df", sw=2)
text(pax + 20, pay + 34, "A · Audio: DFPlayer Mini ↔ ESP32 ↔ Lautsprecher",
     size=19, weight="bold")

# ---- ESP32 board (center) ----
ex, ey, ew, eh = 410, 150, 170, 340
rect(ex, ey, ew, eh, BOARD, rx=14)
rect(ex + ew / 2 - 34, ey + 14, 68, 40, "#cfd3da", rx=4)   # antenna/can
rect(ex + 30, ey + 70, ew - 60, 150, BOARD_DK, rx=8)       # chip
text(ex + ew / 2, ey + 158, "ESP32", size=22, anchor="middle",
     fill="#eef2ee", weight="bold")
rect(ex + ew / 2 - 22, ey + eh - 36, 44, 24, "#1b1b1b", rx=4)  # usb
text(ex + ew / 2, ey + eh - 19, "USB", size=11, anchor="middle", fill="#cfd3da")

# ESP right-side pins used by the DFPlayer (top group)
esp_pins_R = [
    ("5V",     "5v"),
    ("GND",    "gnd"),
    ("G23 (TX2)", "rx"),   # ESP TX -> DFPlayer RX
    ("G22 (RX2)", "tx"),   # ESP RX -> DFPlayer TX
    ("G4",     "busy"),
]
esp_pin_y = {}
py0 = ey + 90
for i, (name, key) in enumerate(esp_pins_R):
    yy = py0 + i * 46
    esp_pin_y[name] = yy
    pin(ex + ew, yy)
    text(ex + ew - 10, yy + 5, name, size=13, anchor="end",
         fill="#eef2ee", font=MONO)

# ---- DFPlayer Mini (right) ----
dx, dy, dw, dh = 700, 150, 150, 300
rect(dx, dy, dw, dh, DFP, rx=12)
text(dx + dw / 2, dy + 26, "DFPlayer", size=17, anchor="middle",
     fill="#eaecf7", weight="bold")
text(dx + dw / 2, dy + 44, "Mini", size=14, anchor="middle", fill="#c4cae8")
rect(dx + 24, dy + 58, dw - 48, 86, DFP_DK, rx=6)   # SD slot
text(dx + dw / 2, dy + 106, "microSD", size=12, anchor="middle", fill="#aeb6df")

# DFPlayer left-side pins (facing the ESP)
dfp_pins = [
    ("VCC",  "5v"),
    ("RX",   "rx"),
    ("TX",   "tx"),
    ("BUSY", "busy"),
    ("GND",  "gnd"),
]
dfp_pin_y = {}
dy0 = dy + 180
for i, (name, key) in enumerate(dfp_pins):
    yy = dy0 + i * 26
    dfp_pin_y[name] = yy
    pin(dx, yy)
    text(dx + 12, yy + 4, name, size=12, anchor="start",
         fill="#eaecf7", font=MONO)

# DFPlayer speaker pins (bottom edge -> speaker)
spk_pins = [("SPK1", dx + 40), ("SPK2", dx + dw - 40)]
for name, xx in spk_pins:
    pin(xx, dy + dh)
    text(xx, dy + dh + 18, name, size=11, anchor="middle", fill=DFP, font=MONO)

# ---- Speaker (below DFPlayer) ----
sx, sy, sr = dx + dw / 2, dy + dh + 70, 42
parts.append(f'<circle cx="{sx}" cy="{sy}" r="{sr}" fill="{SPK}"/>')
parts.append(f'<circle cx="{sx}" cy="{sy}" r="{sr-14}" fill="#555"/>')
parts.append(f'<circle cx="{sx}" cy="{sy}" r="9" fill="#222"/>')
text(sx, sy + sr + 18, "Lautsprecher", size=12, anchor="middle", fill=MUTE)

# ---- wires ESP <-> DFPlayer ----
# Each ESP pin routes to the matching DFPlayer pin with an orthogonal path.
route = [
    ("5V",        "VCC",  "5v",   612),
    ("G23 (TX2)", "RX",   "rx",   624),
    ("G22 (RX2)", "TX",   "tx",   636),
    ("G4",        "BUSY", "busy", 648),
    ("GND",       "GND",  "gnd",  664),
]
for esp_name, dfp_name, key, midx in route:
    y1 = esp_pin_y[esp_name]
    y2 = dfp_pin_y[dfp_name]
    wire([(ex + ew, y1), (midx, y1), (midx, y2), (dx, y2)], WIRE[key])

# 1 kΩ series resistor in the DFPlayer RX line (ESP GPIO23 -> DFPlayer RX),
# drawn as an IEC rectangle on the horizontal run just before the RX pin.
rxy = dfp_pin_y["RX"]
parts.append(
    f'<rect x="636" y="{rxy-9}" width="50" height="18" rx="3" '
    f'fill="#f3ead0" stroke="#9a7d2e" stroke-width="2"/>'
)
text(661, rxy - 14, "1 kΩ", size=11, anchor="middle",
     fill="#7a6320", weight="bold")

# speaker wires
wire([(dx + 40, dy + dh), (dx + 40, sy - 6), (sx - 18, sy - 6)], WIRE["spk"])
wire([(dx + dw - 40, dy + dh), (dx + dw - 40, sy + 18), (sx + 18, sy + 18)], WIRE["spk"])

# ---- connection table (left) ----
tx0, ty0 = pax + 24, 200
text(tx0, ty0 - 14, "Audio-Verbindungen", size=15, weight="bold")
audio_rows = [
    ("DFPlayer VCC", "ESP 5V", "5v"),
    ("DFPlayer RX", "ESP GPIO23 (TX2) · 1 kΩ", "rx"),
    ("DFPlayer TX", "ESP GPIO22 (RX2)", "tx"),
    ("DFPlayer BUSY", "ESP GPIO4", "busy"),
    ("DFPlayer GND", "ESP GND", "gnd"),
    ("DFPlayer SPK1/SPK2", "Lautsprecher", "spk"),
]
for i, (a, b, key) in enumerate(audio_rows):
    yy = ty0 + 18 + i * 32
    parts.append(
        f'<rect x="{tx0}" y="{yy-13}" width="14" height="14" rx="3" '
        f'fill="{WIRE[key]}"/>'
    )
    text(tx0 + 24, yy, a, size=13, font=MONO)
    text(tx0 + 24, yy + 14, "→ " + b, size=12, fill=MUTE, font=MONO)
    ty0 += 14
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

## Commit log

2025-08-04 add numbers
    [list_5x5_with_Numbers.xlsx]
2025-08-04 added docu
    [body.stl, list_5x5_1.csv, list_5x5_2.csv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]
2025-08-07 add tray stl
    [soundboard_tray.stl]
2026-06-13 Add 6-bank mode system, BUSY-pin playback check, BT bank protocol
    - Y key becomes a mode button: tap/hold selects bank pairs (6 banks,
    144 tracks); mode resets after each played sound, 10s, or re-press
    - Read DFPlayer BUSY pin (GPIO4) instead of blocking isPlaying() query
    - DFPlayer init retries then reboots instead of hanging forever
    - Non-blocking BT reader with fixed buffer (no String heap churn)
    - BT protocol mirrors keypad: 101-106 select bank, 1-24 play key
    - Switch DFPlayer to HardwareSerial UART2; drop EspSoftwareSerial
    - Bump platform to espressif32@^7.0.1; update README and AGENTS.md
    [main.cpp]
2026-06-13 Add MP3 sorter desktop tool (Electron, cross-platform)
    Drag-and-drop tool to organise the soundboard MP3s for the DFPlayer:
    - 6 banks shown as box-faithful 5x5 grids (A bottom-left, Y = mode, blocked)
    - physical key colour coding (lib/key-colors.json) as pastel cell backgrounds
    - per-cell play/pause preview (single player; only current track keeps position)
    - swap-vs-shift move dialog; draft autosave; collision-safe two-phase rename
    - A4-landscape PDF export + preview (6 bank lines per cell, no heading)
    - bank*100+pos naming (0101..0624); naming logic unit-tested + Electron smoke test
2026-06-13 Number tracks bank*100+pos; BT commands at 9999 descending
    Encode the bank into the track number for clarity on the SD card:
    bank 1 = 0101..0124, bank 2 = 0201..0224, ... bank 6 = 0601..0624.
    - keypad: track = (bankIndex + 1) * 100 + key
    - Bluetooth: send the track number directly (101..624); bank-select removed
    - BT command codes moved to 9999 and descending (stop/volume/reset) so they
    never collide with a now-valid track number like 201
    [main.cpp]
2026-06-14 Add Flutter Android app to remote-control the soundboard over Bluetooth
    Bluetooth Classic (SPP) remote for the ESP32 soundboard:
    - native Kotlin SPP platform channel (BluetoothSocket/RFCOMM) — no third-party
    BT plugin, so it builds cleanly with current AGP/Gradle
    - 6 banks, each a box-faithful 5x5 grid coloured by the physical key colours
    - taps send bank*100+pos (101..624); volume/stop/reset use the 9999-down commands
    - permission_handler for runtime BLUETOOTH_CONNECT (paired devices only)
    Builds an installable APK (verified with flutter build apk). Note: build from a
    space-free path, not the repo dir (Gradle dislikes spaces) — see app/README.md.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
2026-06-14 App: compact bank selector with a "Bank" label (1–6)
    The Bank chips were truncating to "Ba"; show plain numbers 1–6 with a leading
    "Bank" label, no checkmark, compact density.
2026-06-14 mp3-sorter: PDF-style grid, parking lot, renamer, SD-card export
    - Rework the main view to one 5x5 key grid with 6 bank lines per key (like the
    PDF): play button per line, no track number, cells coloured by key colour.
    - New data model: 144 slots (gaps allowed) + a parked list. Files without a valid
    bank*100+pos prefix go to the parking lot (rows of 5 boxes x 6 lines, alpha).
    Dragging a file from the grid to the parking lot strips its prefix.
    - Drag & drop: slot<->slot swap, slot->parking (unassign), parking->slot (assign).
    - File renamer (search & replace) behind a button: regex + case-sensitive
    checkboxes (case-insensitive by default), 2-column preview of only affected files.
    - SD-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
2026-06-14 mp3-sorter: quick inline rename of a single title (double-click)
    Double-click a title to edit its name inline (Enter saves, Esc cancels); the
    .mp3 extension is kept and parked titles re-sort. Complements the bulk
    search & replace.
2026-06-14 App: namespace → de._11lein / de.lein11; sorter: Papierkorb + MP3-Tooltip + Titelliste
    App:
    - Kotlin package + namespace moved to de._11lein.soundboard_remote
    - applicationId set to de.lein11.soundboard_remote
    - compileSdk 36 forced for all subprojects (file_picker dependency)
    - Liste-Tab: import track list JSON, display titles, play by number
    - New APK (46.8 MB) committed as app/soundboard-remote.apk
    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
2026-06-14 app/README: Installationsanleitung für Android (APK) und iOS-Hinweis
    Erklärt die direkte APK-Installation (Sideload) Schritt für Schritt,
    verlinkt auf Google-Hilfe. Erläutert warum iOS nicht funktioniert
    (SPP/RFCOMM nicht verfügbar) und nennt zwei Alternativen (BLE, WLAN).
2026-06-14 app: custom icon – 5×5 Soundboard-Raster auf dunklem Hintergrund
    SVG-Quelldesign in docs/icon.svg. Alle Android-Mipmap-Größen (mdpi–xxxhdpi)
    als PNG generiert. Adaptive Icon (mipmap-anydpi-v26) für Android 8+:
    Foreground-Ebene (Grid auf Transparent) + Hintergrundfarbe #1E1F24.
    Reihenfarben von oben: Grün, Gelb, Weiß, Blau, Schwarz (2. Taste Rot).
    MODE-Taste (oben rechts) ausgegraut mit gestricheltem Rahmen.
2026-06-14 ESP: WiFi-Radio deaktivieren; App: Liste mit Suche + Bank/Position
    Firmware:
    - esp_wifi_stop()/deinit() im Setup – WiFi wird nie genutzt, Radio bleibt
    garantiert aus (kein Strom, kein 2.4-GHz-Interferenz mit BT). Bewusst nur
    ESP-IDF-Aufrufe statt <WiFi.h>, das die Partition sprengen würde (+190 KB).
    App – Liste-Tab:
    - Suchfeld: filtert nach Titel oder Tracknummer, mit Clear-Button
    - Jede Zeile zeigt jetzt die 3-stellige Tracknummer (101–624) und als
    Untertitel „Bank N · Taste NN"
    - Leerer-Treffer-Hinweis bei erfolgloser Suche
    [main.cpp]
2026-06-14 Optimierungen: ESP NVS-Volume + Connect-Greeting + robuster BT-Reader; App Auto-Reconnect + Haptik; Sorter größere Schrift
    Firmware (src/main.cpp):
    - Lautstärke wird in NVS (Preferences) gespeichert und beim Booten
    wiederhergestellt (applyVolume() statt direktem volume()).
    - Beim BT-Verbindungsaufbau sendet der ESP einmal "READY vol=<n>"
    (SPP-Callback setzt ein Flag, loop() sendet) – App kennt den Stand.
    - BT-Reader verwirft zu lange Zeilen sauber bis zum nächsten '\n',
    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
2026-06-14 README: neuer Verdrahtungsplan mit DFPlayer Mini + BUSY-Pin
    Der alte Wokwi-Screenshot (docu/Schaltung.jpg) nutzte ein microSD-
    Kartenmodul als Platzhalter, zeigte einen Buzzer statt Lautsprecher
    und enthielt den BUSY-Pin nicht.
    Neuer, sauberer Schaltplan (docu/wiring_diagram.png) mit zwei Panels:
    - Audio: DFPlayer Mini ↔ ESP32 ↔ Lautsprecher inkl. BUSY → GPIO4
    - Tastenmatrix 5×5 mit Reihen-/Spalten-GPIOs
    Pin-Belegung direkt aus src/main.cpp abgeleitet. Quelle als SVG plus
    Generator-Skript (docu/gen_wiring.py) beigelegt, damit der Plan bei
    Änderungen reproduzierbar neu erzeugt werden kann. Alten Screenshot
    entfernt und README-Verweise angepasst.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
    [gen_wiring.py]
2026-06-14 Schaltplan + README: 1 kΩ-Vorwiderstand in der DFPlayer-RX-Leitung
    ESP-TX (GPIO23) → DFPlayer-RX läuft jetzt über einen 1 kΩ-Widerstand
    in Reihe (Störungsdämpfung/Eingangsschutz). Im Diagramm als IEC-
    Rechteck auf der RX-Leitung dargestellt, in der Verbindungstabelle
    und der README-Pintabelle ergänzt.
2026-06-14 App: „Berechtigung fehlt" beim Verbinden beheben
    Ursache: adapter.cancelDiscovery() im nativen connect() braucht auf
    Android 12+ die separate BLUETOOTH_SCAN-Berechtigung und warf sonst
    eine SecurityException, die den gesamten Verbindungsaufbau abbrach
    (obwohl BLUETOOTH_CONNECT erteilt war). Wir scannen nicht, daher wird
    der Aufruf jetzt in try/catch gekapselt und ignoriert.
    Zusätzlich robusterer Permission-Flow:
    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
2026-06-15 App+Firmware: Prozent-Lautstärke, Auto-Reconnect, Zufalls-Ton, UI-Feinschliff
    - Lautstärke jetzt in Prozent (0–100 %) statt DFPlayer-Stufen; in NVS
    gespeichert. Neues BT-Kommando 7000+pct setzt die exakte Prozent-
    Lautstärke (auf 0–30 gemappt). READY-Greeting meldet vol=<pct>.
    Alt-Kommandos 9996/97/98 → 100/67/33 % (Kompatibilität).
    App – Verbindung:
    - Watchdog pollt alle 1,2 s den realen Link → AppBar-Icon bleibt aktuell
    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
2026-06-15 App: schnelle Verbindungsanzeige, Reconnect+X-Flow, scrollfreies quadratisches Raster
    Verbindungsanzeige (Icon oben rechts):
    - Nativer Lese-Thread erkennt einen abgerissenen Link sofort (read() == -1
    / IOException → "disconnected" an Dart), statt nur auf den nächsten
    fehlgeschlagenen Write zu warten.
    - Watchdog-Polling von 1,2 s auf 0,7 s verkürzt → Icon spiegelt den
    Zustand binnen ~1 s.
    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
2026-06-15 App: Connection-Bar ohne Spinner – Status-Button (Verbunden/Reconnect/ausgegraut)
    Der untere Lade-Spinner ist weg. Stattdessen ein einziger Primär-Button,
    der den Zustand zeigt:
    - verbunden → „Verbunden" (Tippen trennt)
    - getrennt → „Reconnect (<Gerät>)" bzw. „Verbinden" ohne gespeichertes Gerät
    - verbindend → ausgegraut/deaktiviert „Verbinde…"
    Der X-Button „Anderes Gerät wählen" bleibt (verbunden oder mit letztem Gerät).
2026-06-15 App: Fehler als Toast statt Statuszeile – Connection-Bar springt nicht mehr
    Die variable Statuszeile links neben dem Verbinden-Button verschwindet.
    Der Button füllt jetzt die Breite (fixes Layout, kein Springen mehr).
    Fehler (Verbindung fehlgeschlagen, Sendefehler, fehlende Berechtigung,
    Geräteliste) landen in controller.errorMessage und werden vom HomePage-
    Listener einmalig als rote SnackBar/Toast angezeigt und konsumiert.
2026-06-15 App: X-Button immer sichtbar (Trennen/Abbrechen), kein Flackern beim Verbinden
    - Der X-Button ist jetzt dauerhaft an fester Position. Bei Verbindung oder
    laufendem Versuch trennt/bricht er ab, sonst öffnet er die Geräteauswahl.
    Icon bleibt konstant → kein Layout-Springen mehr.
    - Stille Hintergrund-Reconnects ändern den sichtbaren Zustand nicht mehr:
    nur vom Nutzer ausgelöste Verbindungen zeigen „Verbinde…". Damit springt
    der Button nicht mehr zwischen „Reconnect" und „Verbinde…".
    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
2026-06-15 App: Vibrationsfeedback verstärkt und auf mehr Bedienelemente erweitert
    - Sound-Tasten (Raster, Zufall, Liste) von selectionClick auf mediumImpact
    – deutlich spürbar statt kaum merklich.
    - STOP: heavyImpact.
    - Lautstärke (−5/100/+5) und Bank-Auswahl: leichter selectionClick-Tick
    (über _haptic-Helper).
    Hinweis: Haptik nutzt das System-Feedback und respektiert die Geräte-
    Einstellung „Touch-Vibration".
2026-06-15 App: echtes Vibrationsfeedback via vibration-Package (unabhängig von Touch-Haptik)
    Ersetzt Flutter HapticFeedback (von der System-Touch-Vibration stummschaltbar)
    durch direkte Motoransteuerung mit VIBRATE-Permission.
    - Neues Haptics-Utility (lib/haptics.dart): init() prüft Vibrator/Amplitude,
    light()/medium()/heavy() feuern mit Dauer+Stärke.
    - Sound-Tasten (Raster/Zufall/Liste) → medium, STOP → heavy,
    Lautstärke/Bank → light.
    - vibration ^3.1.3 (3.2.0 aufgelöst), VIBRATE-Permission im Manifest.
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2026-06-15 Firmware-Tuning: Play-on-Press (Hybrid) + verzögertes NVS-Volume
    - Soundtasten spielen jetzt beim DRÜCKEN (Bank A der Gruppe) statt beim
    Loslassen → spürbar geringere Latenz. Wird die Taste gehalten (≥250 ms,
    HOLD_TIME von 500→250), wird auf Bank B umgeschaltet. Same-Key-Stop-Toggle
    + Mode-Reset nach dem Sound bleiben erhalten.
    - Lautstärke wird nicht mehr bei jedem +5/-5-Schritt ins Flash geschrieben,
    sondern erst 1,5 s nach der letzten Änderung (kein Block durch Flash-Writes
    bei schnellem Tippen).
    [main.cpp]
2026-06-15 Hold-Fix (Play-on-Press ohne Stop-Toggle) + Titel im Belegungs-Popup bearbeiten
    - Same-Key-Stop-Toggle an der Hardware-Taste entfernt. Er kollidierte mit dem
    Halten (beim Drücken nicht unterscheidbar von "Stop") und hing am
    unzuverlässigen BUSY-Pin. Jetzt: Tippen = sofort Bank A, Halten = Bank B,
    nochmal drücken = neu starten. Stop läuft über die App.
    - Im 6-Bank-Belegungs-Popup (Long-press auf eine Taste) kann ein Eintrag mit
    Titel jetzt selbst lang gedrückt werden, um den Titel zu bearbeiten
    (persistiert, wie in der Liste).
    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
    [main.cpp]
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2026-06-16 Sorter: 700+ Titel beim Import übernehmen (Bug), Import-Diff zum Bestätigen, Button-Labels
    - BUG: applyImportedList mappte nur Slots 101–624; 700+ (Parkplatz-)Titel
    wurden ignoriert (daher „144 übernommen"). Jetzt mappt entryForNumber 700+
    auf den jeweiligen Parkplatz (n−700), Parkplätze werden danach neu sortiert.
    - Listen-Import zeigt jetzt eine Diff-Vorschau (alt → neu) zum Bestätigen,
    Statusmeldung nennt die Zahl der tatsächlichen Umbenennungen.
    - Buttons umbenannt: „Umbenennen" → „🔎 Suchen & Ersetzen“, „Liste“ →
    „📋 Liste exportieren". Import-Button auch bei reinen Parkplätzen aktiv.
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2026-06-16 Sorter: ADB robuster (SDK-Pfad finden + WLAN-Gerät auto-connecten), Export-Optionen untereinander
    - resolveAdb(): findet adb auch ohne PATH über die üblichen SDK-Pfade
    (ANDROID_HOME, ~/Android/Sdk, macOS/Windows-Defaults).
    - ensureAdbDevice(): wenn kein Gerät am adb-Server hängt, wird per
    `adb mdns services` ein WLAN-Gerät gesucht und `adb connect` ausgeführt –
    damit funktioniert Push/Pull auch über WLAN-Debugging ohne Kabel.
    - Klarere Fehlermeldung (stderr) bei fehlendem Gerät.
    - Export-Dialog: Ziel-Checkboxen jetzt untereinander (.opt-col).
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2026-06-16 firmware: clarify BUSY-pin unreliability and stop-toggle comments
    Comment-only changes (no behaviour change): document why isPlaying() is only
    trusted for the same-key stop toggle (the BUSY signal flickers), and why lastKey
    is cleared after a stop. const-correctness on the keypad pin arrays is not
    applied because the Keypad library constructor takes non-const byte* pointers.
    [main.cpp]
2026-06-16 App: Display-Umschalter ins ⋮-Menü, Swipe von letzter Bank in die Liste
    - "Titel statt Nummern" und "Bildschirm anlassen" als checkbare Einträge ins
    ⋮-Menü verschoben und aus der Einstellungsseite entfernt
    - Tasten-Tab: Weiter-Swipe nach rechts auf der letzten Bank-Seite wechselt per
    Overscroll in den Listen-Tab (expliziter TabController statt DefaultTabController)
    - Merge-Fix: Flutters eingebautes KeepAlive im material-Import ausgeblendet
    (Namenskollision mit widgets/keep_alive.dart)
    - AGENTS.md gestrafft + Deploy-Anleitung (ADB-WLAN in-place, ESP-Flash) ergänzt
